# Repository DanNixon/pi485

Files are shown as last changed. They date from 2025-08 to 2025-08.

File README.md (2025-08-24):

# pi485

Simple module for interfacing RS485 devices with an Ethernet network.

## Features

- Two RS485-UART interfaces
- Ethernet (either [WIZ550io](https://docs.wiznet.io/Product/ioModule/wiz550io) or [W5500-EVB-Pico](https://docs.wiznet.io/Product/iEthernet/W5500/w5500-evb-pico))
- SD card
- 5V regulator
- Display and buttons

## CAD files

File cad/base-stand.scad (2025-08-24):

height = 8;
tray_depth = 4;
pcb_thickness = 1.6;

screw_positions = [
  [46.5, 27],
  [46.5, -27],
  [-46.5, -27],
];

difference() {
  union() {
    difference() {
      translate([0, 0, -height]) {
        linear_extrude(height) {
          square([105, 66], center = true);
        }
      }

      translate([0, 0, 0.01 - tray_depth]) {
        linear_extrude(tray_depth) {
          square([101, 62], center = true);
        }
      }
    }

    translate([0, 0, -tray_depth]) {
      for(p = screw_positions) {
        translate(p) {
          cylinder(d = 6, h = abs(tray_depth) - pcb_thickness);
        }
      }
    }
  }

  translate([0, 0, -height - 1]) {
    for(p = screw_positions) {
      translate(p) {
        cylinder(d = 3, h = height + 2);
      }
    }
  }
}

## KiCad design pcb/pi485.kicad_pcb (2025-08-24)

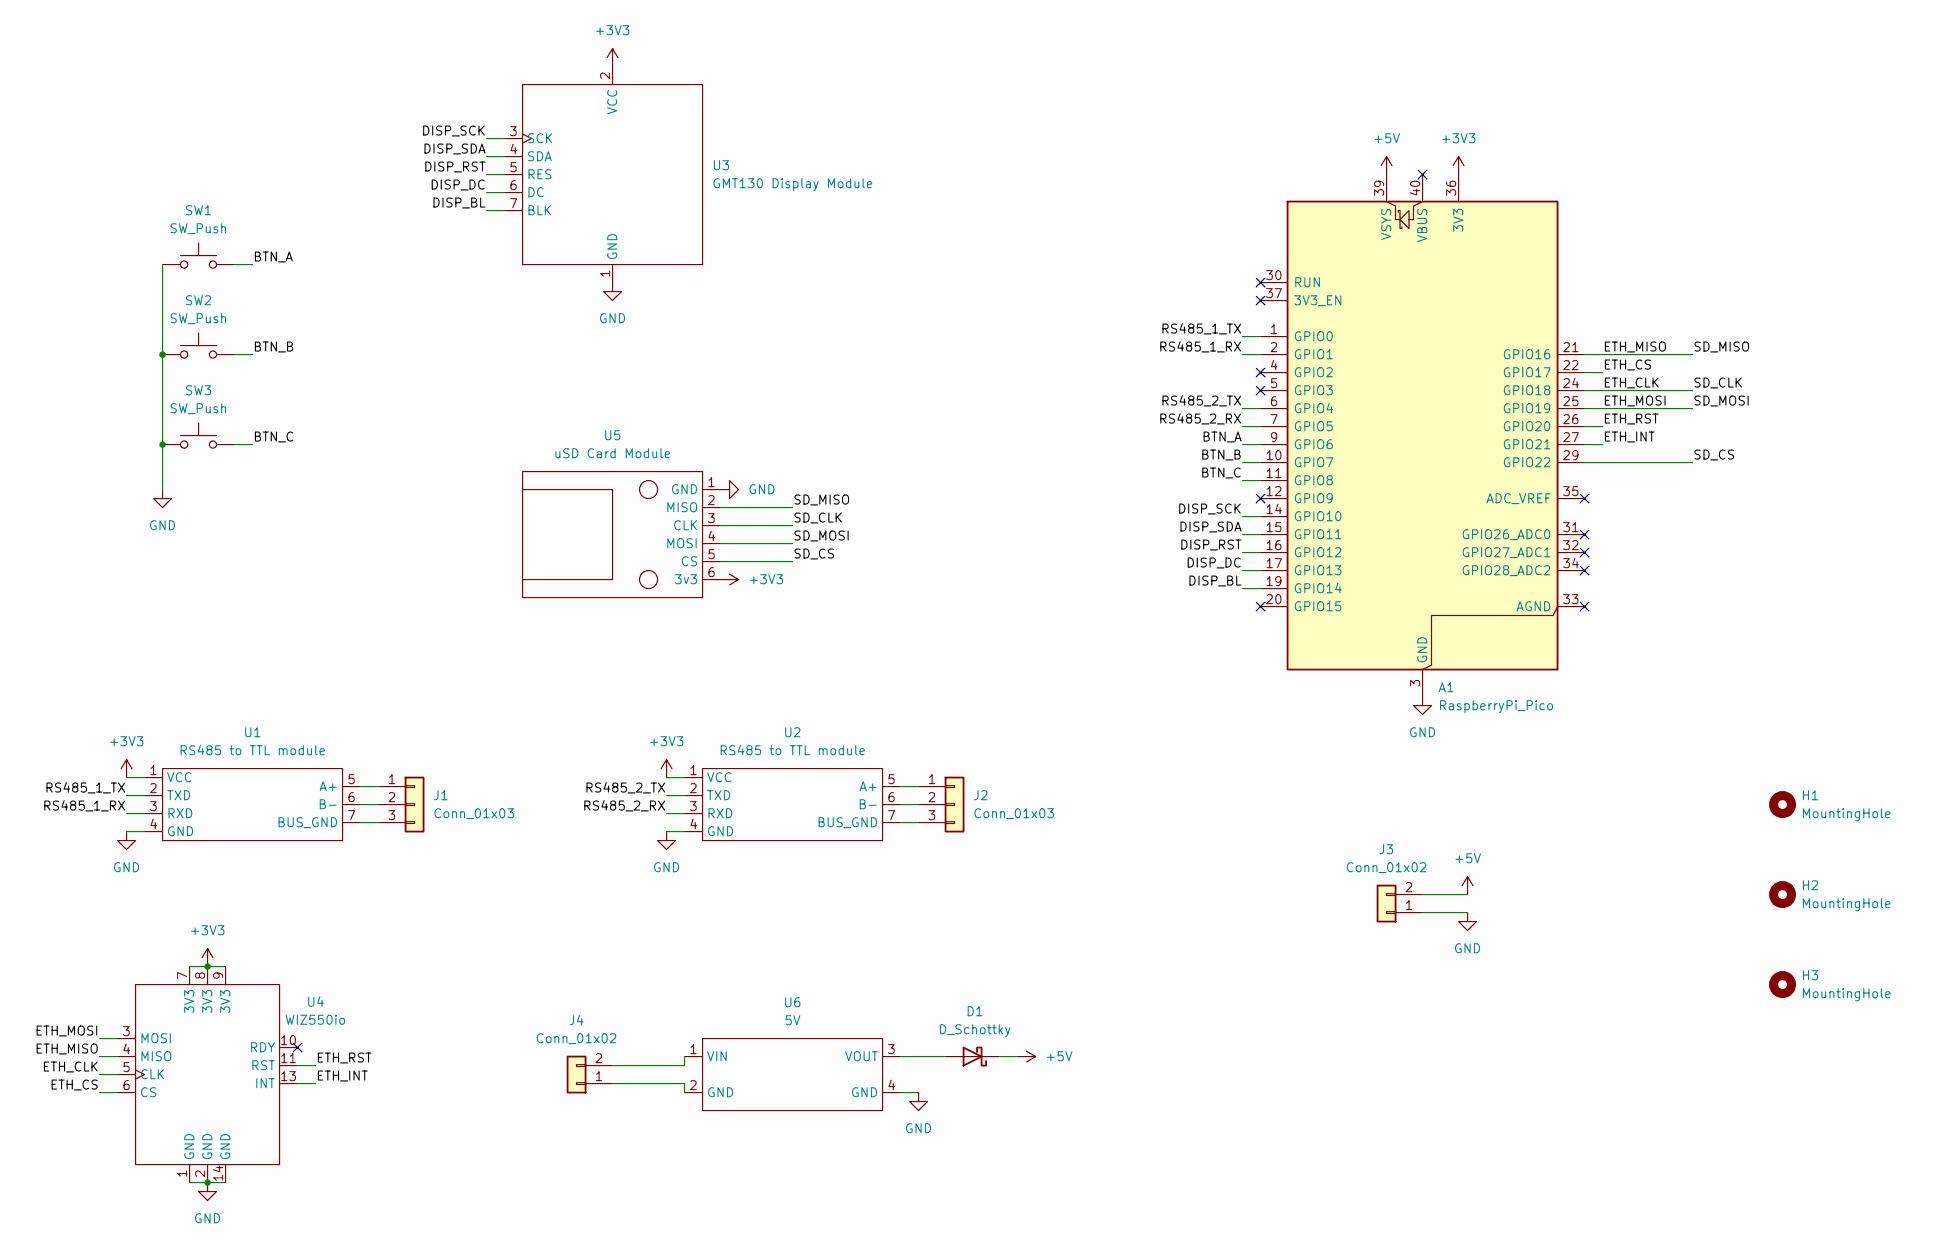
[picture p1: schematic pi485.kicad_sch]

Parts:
A1: RaspberryPi_Pico; RaspberryPi_Pico_Common_THT
D1: D_Schottky; D_SOD-123
H1, H2, H3: MountingHole; MountingHole_3.2mm_M3
J1, J2: Conn_01x03; CTB7000-3
J3, J4: Conn_01x02; ED5552DS
SW1, SW2, SW3: SW_Push; SW_PUSH_6mm
U1, U2: RS485 to TTL module; RS485_to_ttl
U3: GMT130 Display Module; GMT130
U4: WIZ550io
U5: uSD Card Module; uSD_Card
U6: 5V; AliE_MP1584EN_regulator

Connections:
+3V3: A1.36 (3V3), U1.1 (VCC), U2.1 (VCC), U3.2 (VCC), U4.7 (3V3), U4.8 (3V3), U4.9 (3V3), U5.6 (3v3)
+5V: A1.39 (VSYS), D1.1 (K), J3.2
/BTN_A: A1.9 (GPIO6), SW1.2
/BTN_B: A1.10 (GPIO7), SW2.2
/BTN_C: A1.11 (GPIO8), SW3.2
/DISP_BL: A1.19 (GPIO14), U3.7 (BLK)
/DISP_DC: A1.17 (GPIO13), U3.6 (DC)
/DISP_RST: A1.16 (GPIO12), U3.5 (RES)
/DISP_SCK: A1.14 (GPIO10), U3.3 (SCK)
/DISP_SDA: A1.15 (GPIO11), U3.4 (SDA)
/ETH_CLK: A1.24 (GPIO18), U4.5 (CLK), U5.3 (CLK)
/ETH_CS: A1.22 (GPIO17), U4.6 (CS)
/ETH_INT: A1.27 (GPIO21), U4.13 (INT)
/ETH_MISO: A1.21 (GPIO16), U4.4 (MISO), U5.2 (MISO)
/ETH_MOSI: A1.25 (GPIO19), U4.3 (MOSI), U5.4 (MOSI)
/ETH_RST: A1.26 (GPIO20), U4.11 (RST)
/RS485_1_RX: A1.2 (GPIO1), U1.3 (RXD)
/RS485_1_TX: A1.1 (GPIO0), U1.2 (TXD)
/RS485_2_RX: A1.7 (GPIO5), U2.3 (RXD)
/RS485_2_TX: A1.6 (GPIO4), U2.2 (TXD)
/SD_CS: A1.29 (GPIO22), U5.5 (CS)
GND: A1.3 (GND), A1.8 (GND), A1.13 (GND), A1.18 (GND), A1.23 (GND), A1.28 (GND), A1.38 (GND), J3.1, SW1.1, SW2.1, SW3.1, U1.4 (GND), U2.4 (GND), U3.1 (GND), U4.1 (GND), U4.2 (GND), U4.14 (GND), U5.1 (GND), U6.4 (GND)
unnamed: D1.2 (A), U6.3 (VOUT)
unnamed: J1.1, U1.5 (A+)
unnamed: J1.2, U1.6 (B-)
unnamed: J1.3, U1.7 (BUS_GND)
unnamed: J2.1, U2.5 (A+)
unnamed: J2.2, U2.6 (B-)
unnamed: J2.3, U2.7 (BUS_GND)
unnamed: J4.1, U6.2 (GND)
unnamed: J4.2, U6.1 (VIN)

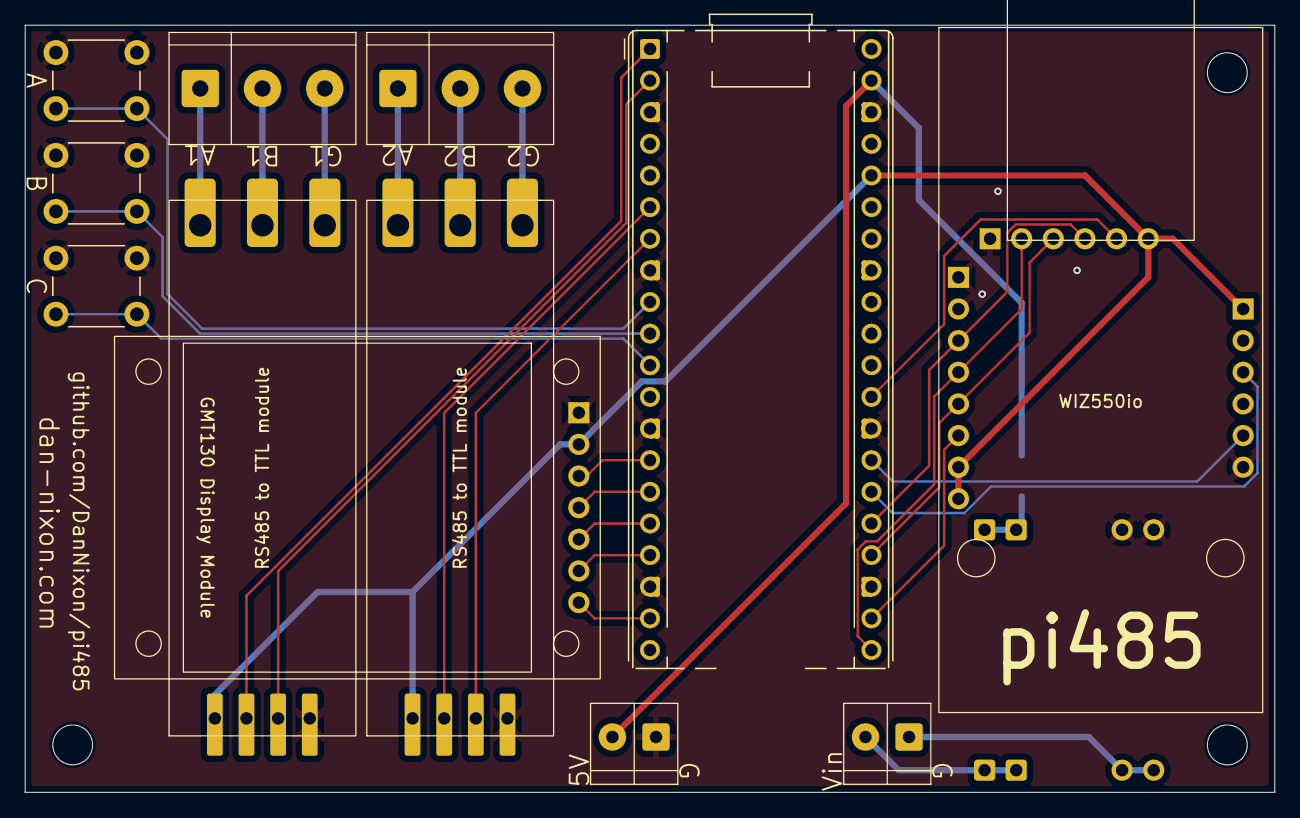
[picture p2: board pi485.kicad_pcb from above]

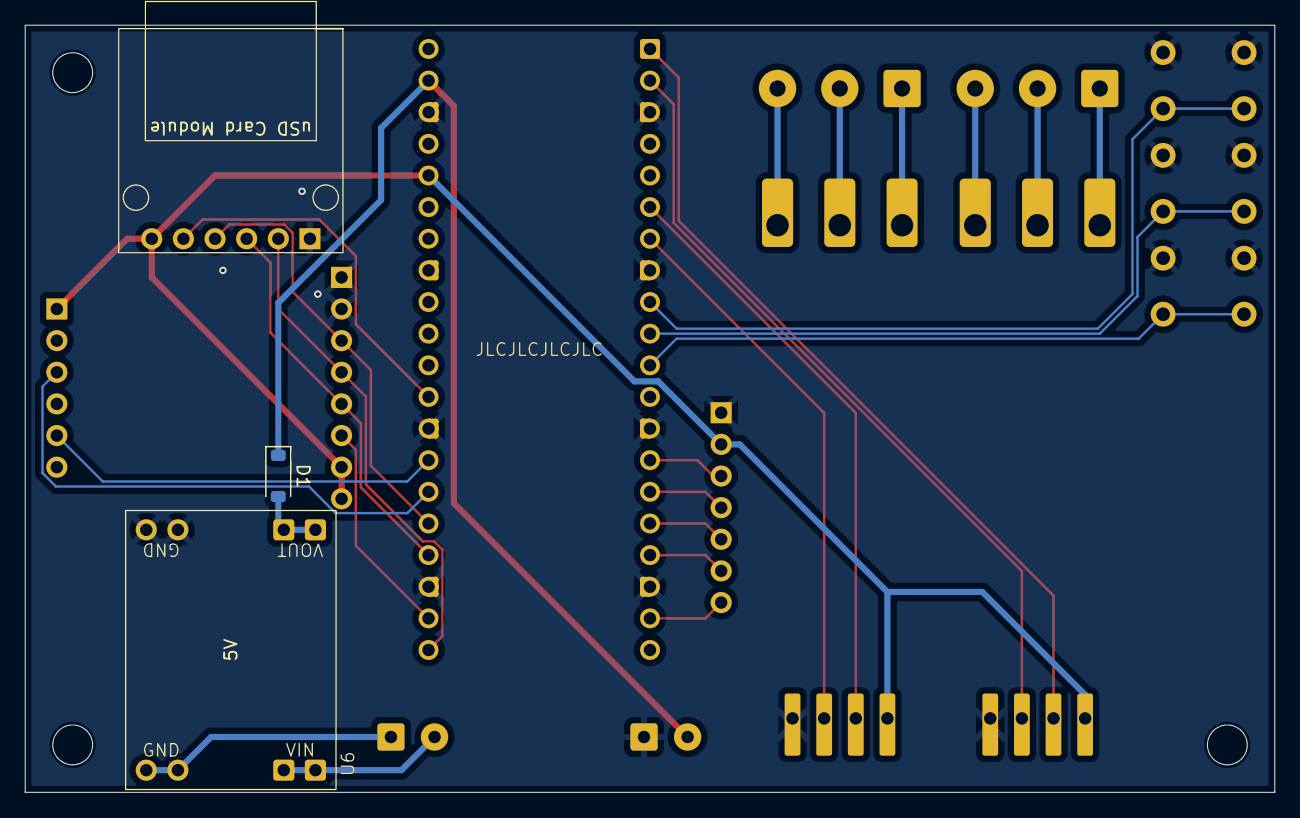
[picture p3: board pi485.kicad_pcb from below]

Board: 2 copper layers, 100.3 x 61.6 mm, 18 parts (3 on the bottom side), 31 nets.

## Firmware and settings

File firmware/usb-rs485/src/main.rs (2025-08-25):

#![no_std]
#![no_main]

mod rs485;
mod usb;

use defmt::info;
use defmt_rtt as _;
use embassy_executor::Spawner;
use embassy_rp::{
    peripherals,
    uart::{Config, DataBits, Parity, StopBits},
    Peri,
};
use embassy_sync::{blocking_mutex::raw::CriticalSectionRawMutex, pubsub::PubSubChannel};
use heapless::Vec;
use panic_probe as _;
use portable_atomic as _;

assign_resources::assign_resources! {
    rs485_uart_0: Rs485Uart0Resources {
        tx_pin: PIN_0,
        rx_pin: PIN_1,
        uart: UART0,
    },
    rs485_uart_1: Rs485Uart1Resources {
        tx_pin: PIN_4,
        rx_pin: PIN_5,
        uart: UART1,
    },
    usb: UsbResources {
        usb: USB,
    },
}

#[embassy_executor::main]
async fn main(spawner: Spawner) {
    let p = embassy_rp::init(Default::default());
    let r = split_resources!(p);

    info!("Hello, world!");

    let uart_config = {
        let mut config = Config::default();
        config.baudrate = 19200;
        config.data_bits = DataBits::DataBits8;
        config.parity = Parity::ParityNone;
        config.stop_bits = StopBits::STOP1;
        config
    };

    spawner.must_spawn(usb::task(spawner, r.usb));
    spawner.must_spawn(rs485::usb_task(spawner, r.rs485_uart_0, uart_config));
    spawner.must_spawn(rs485::echo_task(r.rs485_uart_1, uart_config));
}

pub(crate) type Payload = Vec<u8, 64>;

pub(crate) static USB_TO_RS485: PubSubChannel<CriticalSectionRawMutex, Payload, 8, 1, 1> =
    PubSubChannel::new();
pub(crate) static RS485_TO_USB: PubSubChannel<CriticalSectionRawMutex, Payload, 8, 1, 1> =
    PubSubChannel::new();

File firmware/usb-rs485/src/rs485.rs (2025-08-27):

use crate::{Rs485Uart0Resources, Rs485Uart1Resources};
use defmt::{debug, info, warn};
use embassy_executor::Spawner;
use embassy_rp::{
    bind_interrupts,
    peripherals::{UART0, UART1},
    uart::{BufferedInterruptHandler, BufferedUart, BufferedUartRx, BufferedUartTx, Config},
};
use embassy_sync::pubsub::WaitResult;
use embedded_io_async::{Read, Write};
use heapless::Vec;
use static_cell::StaticCell;

use super::{RS485_TO_USB, USB_TO_RS485};

bind_interrupts!(struct IrqsUart0 {
    UART0_IRQ  => BufferedInterruptHandler<UART0>;
});

bind_interrupts!(struct IrqsUart1 {
    UART1_IRQ  => BufferedInterruptHandler<UART1>;
});

#[embassy_executor::task]
pub(super) async fn usb_task(spawner: Spawner, r: Rs485Uart0Resources, config: Config) {
    const TX_BUFFER_SIZE: usize = 32;
    const RX_BUFFER_SIZE: usize = 32;

    static TX_BUFFER: StaticCell<[u8; TX_BUFFER_SIZE]> = StaticCell::new();
    let tx_buf = &mut TX_BUFFER.init([0; TX_BUFFER_SIZE])[..];

    static RX_BUFFER: StaticCell<[u8; RX_BUFFER_SIZE]> = StaticCell::new();
    let rx_buf = &mut RX_BUFFER.init([0; RX_BUFFER_SIZE])[..];

    let uart = BufferedUart::new(
        r.uart, r.tx_pin, r.rx_pin, IrqsUart0, tx_buf, rx_buf, config,
    );

    let (tx, rx) = uart.split();

    spawner.must_spawn(tx_task(tx));
    spawner.must_spawn(rx_task(rx));
}

#[embassy_executor::task]
async fn tx_task(mut tx: BufferedUartTx) {
    let mut subscriber = USB_TO_RS485.subscriber().unwrap();

    loop {
        match subscriber.next_message().await {
            WaitResult::Lagged(_) => {
                warn!("Subscriber lagged");
            }
            WaitResult::Message(msg) => {
                if let Err(e) = tx.write(&msg).await {
                    warn!("Failed writing to UART: {}", e);
                }
            }
        }
    }
}

#[embassy_executor::task]
async fn rx_task(mut rx: BufferedUartRx) {
    let publisher = RS485_TO_USB.publisher().unwrap();

    let mut buf = [0u8; 64];

    loop {
        let n = rx.read(&mut buf).await.unwrap();
        debug!("Read {} bytes on UART", n);

        let data = &buf[..n];
        info!("RS485->USB: {:x}", data);

        let vec = Vec::from_slice(data).unwrap();
        publisher.publish(vec).await;
    }
}

#[embassy_executor::task]
pub(super) async fn echo_task(r: Rs485Uart1Resources, config: Config) {
    const TX_BUFFER_SIZE: usize = 32;
    const RX_BUFFER_SIZE: usize = 32;

    static TX_BUFFER: StaticCell<[u8; TX_BUFFER_SIZE]> = StaticCell::new();
    let tx_buf = &mut TX_BUFFER.init([0; TX_BUFFER_SIZE])[..];

    static RX_BUFFER: StaticCell<[u8; RX_BUFFER_SIZE]> = StaticCell::new();
    let rx_buf = &mut RX_BUFFER.init([0; RX_BUFFER_SIZE])[..];

    let mut uart = BufferedUart::new(
        r.uart, r.tx_pin, r.rx_pin, IrqsUart1, tx_buf, rx_buf, config,
    );

    let mut buf = [0u8; 64];

    loop {
        let n = uart.read(&mut buf).await.unwrap();
        debug!("Read {} bytes on UART", n);
        let data = &buf[..n];
        uart.write(data).await.unwrap();
    }
}
